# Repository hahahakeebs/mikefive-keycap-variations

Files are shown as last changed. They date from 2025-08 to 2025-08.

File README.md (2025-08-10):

# MikeFive Keycap Variations

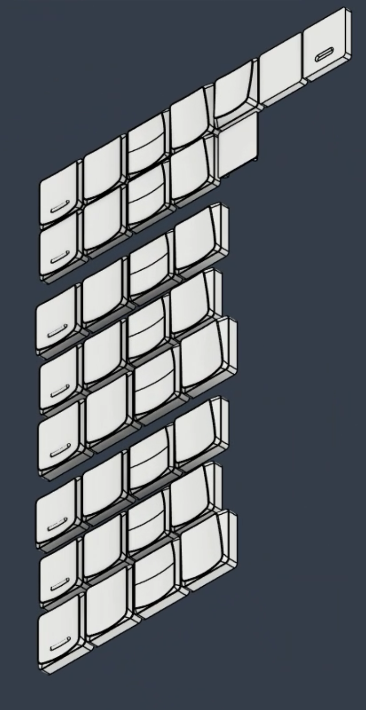
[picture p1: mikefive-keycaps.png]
image of the keycap variations included in this repository


I really liked these [keycaps](https://github.com/mikeholscher/zmk-config-mikefive/tree/main/files/custom-keycaps), so I ported the keywell versions to PG1425, Choc V1, and MX/Choc V2 in various spacings. I also added a homing bar to the middle row key for a homing version. I've also included Kailh's stock flat (and unappealing) PG14 keycaps with a divot added for homing, but they still suck and are only provided for completion's sake, or because I'm too lazy to remove them from the step files. Take your pick.

## PG1425

### Two Part Cap (for FDM printing)

This port requires some extra work to get right. The tolerances on the clips for these switches are vanishingly small, and the clips themselves are _tiny_. I wasn't able to get them to fit on the switches (and/or not to prevent the switch from returning) unless I printed them flat on the print bed. This, shockingly, does not produce a very comfortable or appealing keycap, so I decided to make them two-piece, so the tops can be printed vertically with minimal supports for an appealing digital interface. The keycap tops are meant to be superglued onto the clips. Best practice I found was to mount the clips to the switches, apply CA glue to the underside of the keycap top, and then place them on top of the clip.

### Single Cap (for MJF printing)

I wanted to see if JLC's MJF process could handle the tolerances needed for the clips without having to separate the clips from the keycap surface, so I ordered some, and they turned out pretty well. The keycap walls are either at or under the tolerances JLC requires for the method, so there can be imperfections. Buy extras if this will bother you, but otherwise they fit and worked as well as I could have hoped.

Update: I added sprued versions of the single cap for easier jlc ordering.

Credit for design goes to [Mike Holscher](https://github.com/mikeholscher), thanks for putting mikefive/mikecinq/this keycap profile out into the world!

These have been produced and tested, do what thou wilt. Don't expect support beyond a silent, empathetic, but also awkward hug if these keycaps burn down your house or something.

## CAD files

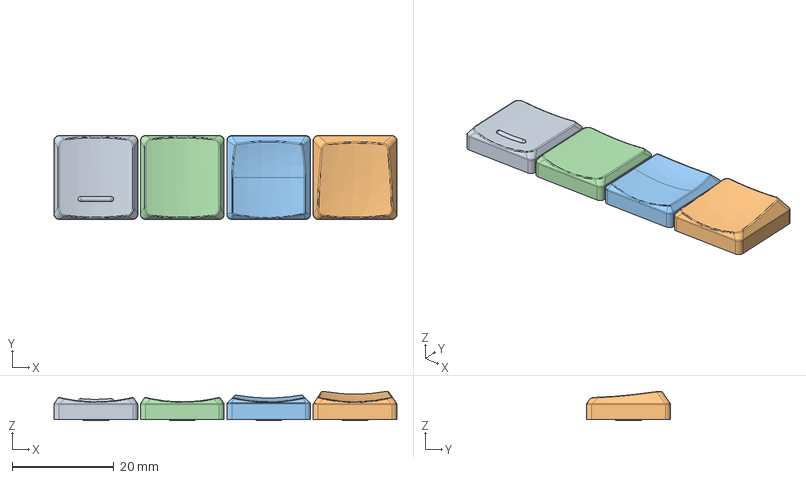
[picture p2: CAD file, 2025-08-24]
MK5 keycaps v35 choc v2 cfx spacing.step
67.5 x 16.5 x 5.75 mm

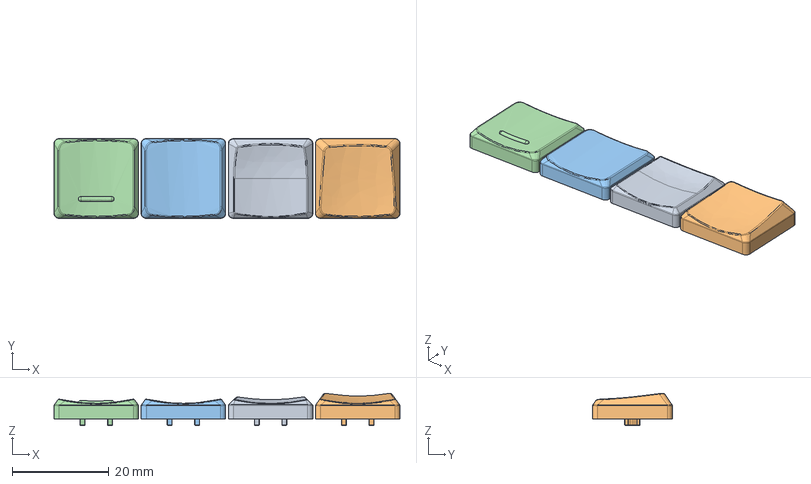
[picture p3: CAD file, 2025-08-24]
MK5 keycaps v35 choc v1 choc spacing.step
71.6 x 16.5 x 6.66 mm

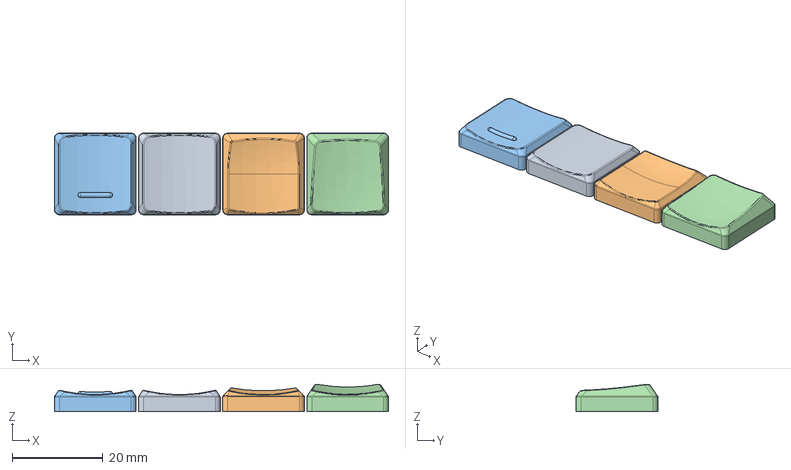
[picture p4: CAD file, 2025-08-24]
MK5 keycaps v35 choc v2 mx spacing.step
73.6 x 18.0 x 6.01 mm

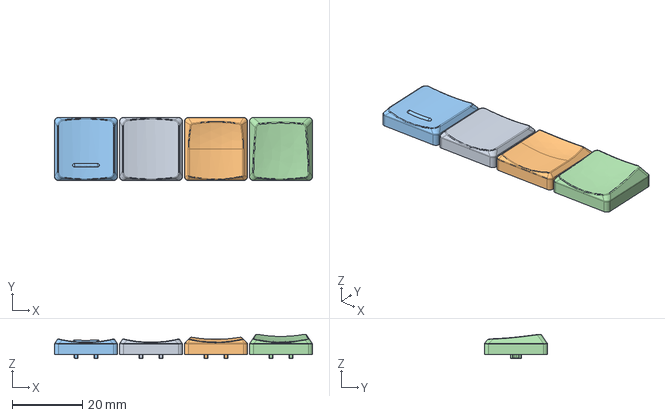
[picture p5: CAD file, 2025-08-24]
MK5 keycaps v35 choc v1 mx spacing.step
73.6 x 18.0 x 6.92 mm

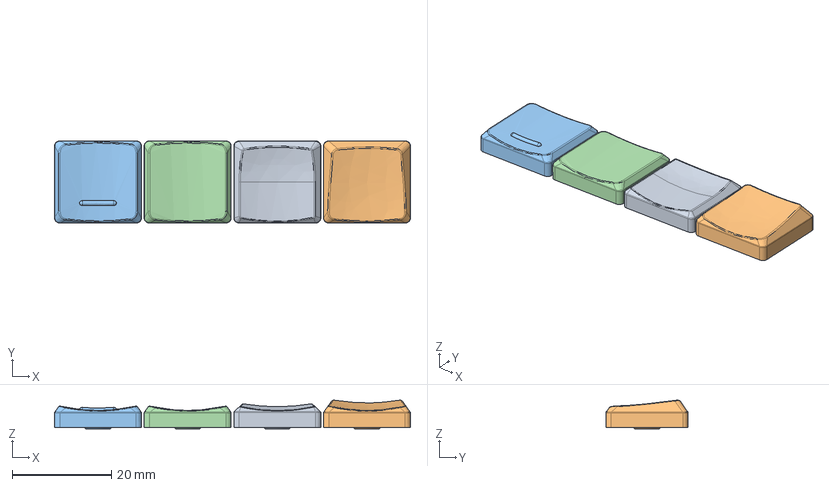
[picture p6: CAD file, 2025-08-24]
MK5 keycaps v35 choc v2 choc spacing.step
71.6 x 16.5 x 5.75 mm

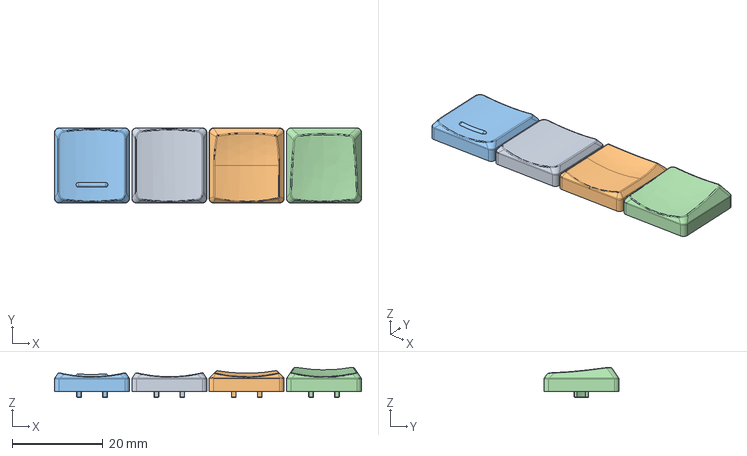
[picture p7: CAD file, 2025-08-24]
MK5 keycaps v35 choc v1 cfx spacing.step
67.5 x 16.5 x 6.66 mm

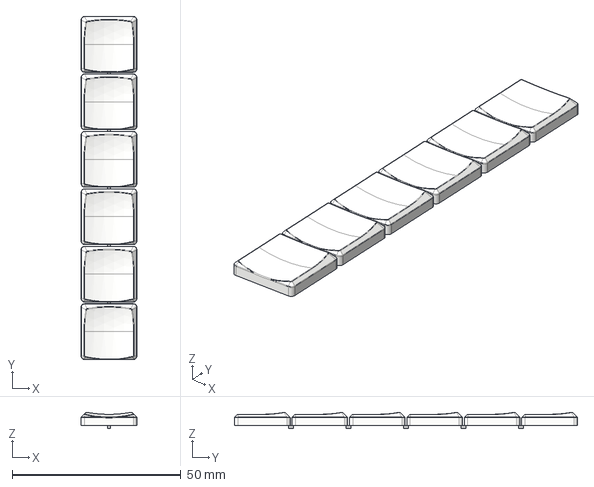
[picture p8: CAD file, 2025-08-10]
MK5 1425 6x sprued thumbs.step
16.5 x 101.5 x 4.83 mm

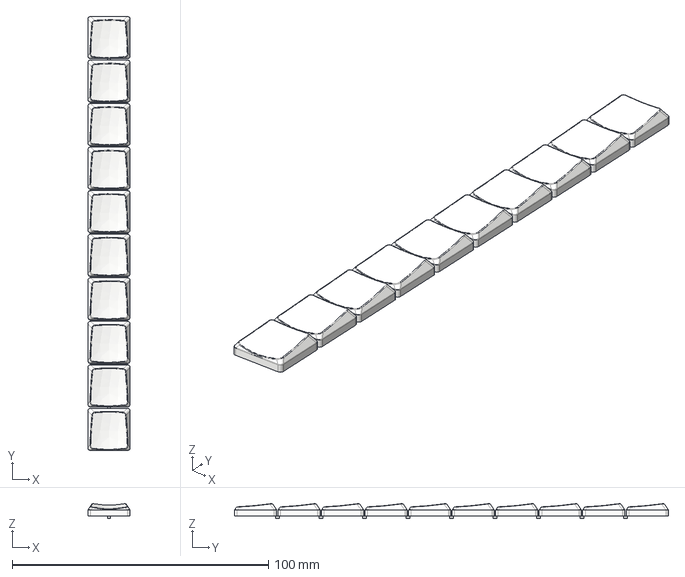
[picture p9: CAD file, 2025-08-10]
MK5 1425 10x sprued angled top.step
16.5 x 169.5 x 5.72 mm

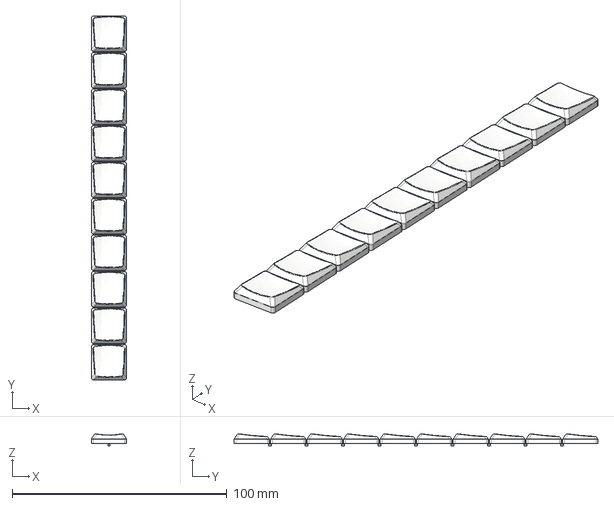
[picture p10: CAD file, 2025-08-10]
MK5 1425 10x sprued angled bottom.step
16.5 x 169.5 x 5.72 mm

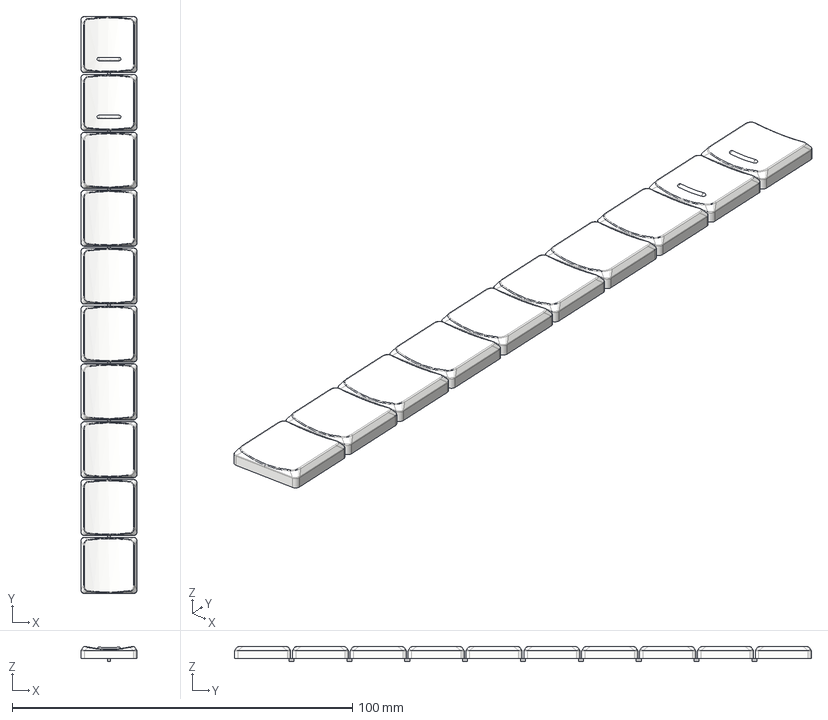
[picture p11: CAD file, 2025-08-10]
MK5 1425 sprued home row with homing 8x2.step
16.5 x 169.5 x 4.54 mm

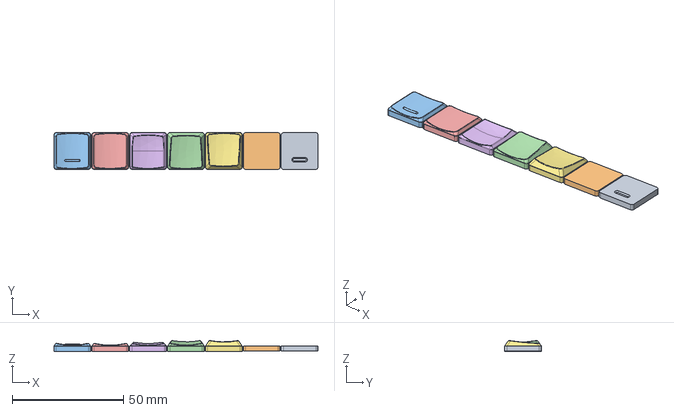
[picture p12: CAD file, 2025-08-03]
MK5 keycaps v31 1425 1 piece for mjf.step
118.5 x 16.5 x 4.84 mm

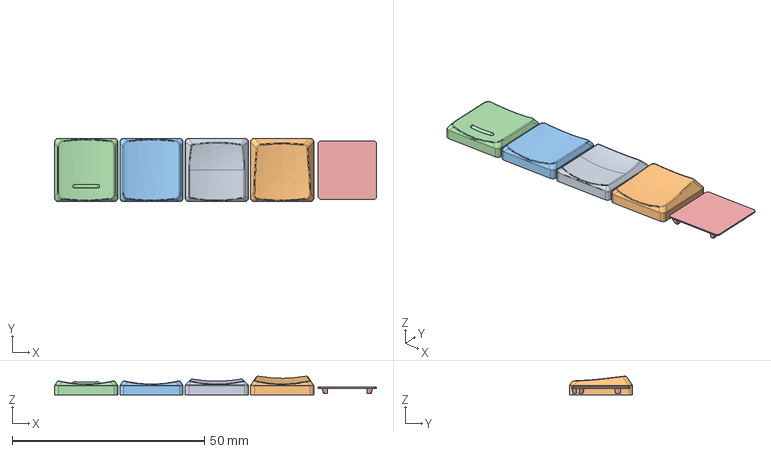
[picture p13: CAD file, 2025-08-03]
MK5 keycaps v31 1425 2 piece for fdm.step
83.8 x 16.5 x 4.84 mm

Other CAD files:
MK5 keycaps v35 choc v2 choc spacing.3mf

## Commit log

2025-08-10 add jlc sprues
    [MK5 1425 10x sprued angled bottom.step, MK5 1425 10x sprued angled top.step, MK5 1425 6x sprued thumbs.step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]
2025-08-24 new version
    [MK5 keycaps v31 Choc V1 CFX Spaced.step, MK5 keycaps v31 Choc V1 Choc Spaced.step, MK5 keycaps v31 Choc V1 MX Spaced.step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]
